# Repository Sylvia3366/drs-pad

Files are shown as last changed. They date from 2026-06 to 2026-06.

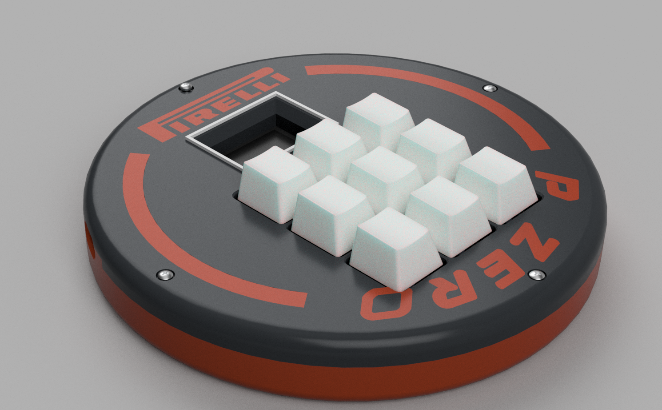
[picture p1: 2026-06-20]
images/drspad_RENDER.png

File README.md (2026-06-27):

# DRS-Pad 🏎️💨
reallygreatsite com

[ONSHAPE CAD](https://cad.onshape.com/documents/f871e0d794d92113bb05b77c/w/53d91f0d4610f412f5f57ae5/e/b5381f3e555c04c2681f8eeb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)
-

What is it? 
-
The DRS-Pad, or Desktop Response System Pad, is a macropad powered by the XIAO-ESP32-S3 with 9 mechanical keys to save your fingers and hasten your workflow so you can be more efficient! Named after the now retired DRS (Drag Reduction System, RIP 2011–2025), the DRS-Pad is modeled after the iconic F1 Pirelli tire (specifically the soft one). Paired with a 1.14" IPS LCD display, it allows you to view race/qualifying results on race/qualification days and WDC/WCC standings on non-race days.

Why did I make it? 
-
First and foremost, I've been wanting to make a macropad for the longest time now. I'm someone who's constantly on my computer—whether it be writing stories, programming/playing games, editing videos, or just doing homework, my fingers are constantly jumping around my keyboard. As a result, I often end the day with cramped fingers, so hopefully, this macropad will solve that :(

As for the theme: I've been an F1 fan for some time now, and I've grown a habit of checking my phone and social media for race updates. But I simply can't do that when I'm in the middle of working on CADing or programming. So I thought, what if I could combine both those problems into one solution?

How does it work?
-
So I made the DRS-Pad! Aside from being your usual, run-of-the-mill macropad for improving workflow and allowing your fingers to rest, there's a little screen that updates you on the latest F1 standings in real time! On a typical, non-race or quali day, the DRS-Pad will flicker between the WDC (driver's championship) and WCC (constructor's championship) every minute. During free practice, quali, and race days, the screen will update every minute with live feed on the current event, displaying the top 9 drivers. This is done through using an open source API **(https://openf1.org)**.

Now, you can save your fingers AND enjoy some nice F1 updates all at the same time :)!

# Designing the PCB 🏁
PCB designed on KiCAD!
-
Screenshot 2026-06-18 at 11 29 14 PM

Screenshot 2026-06-19 at 9 13 22 PM

Screenshot 2026-06-19 at 9 14 33 PM
Screenshot 2026-06-19 at 9 14 27 PM

CADed and assembled on OnShape!
-
Screenshot 2026-06-19 at 9 16 24 PM
Screenshot 2026-06-19 at 9 15 55 PM

Screenshot 2026-06-19 at 9 16 43 PM
Screenshot 2026-06-19 at 9 16 55 PM

Screenshot 2026-06-19 at 9 17 05 PM
Screenshot 2026-06-19 at 9 17 11 PM

Rendered on Fusion360!
-
Screenshot 2026-06-19 at 6 39 32 PM
Screenshot 2026-06-19 at 8 05 35 PM

# Bill of Materials 🧾
| Name | Qty | Unit | Price (USD) | Total (USD) | MOQ | MOQ Price | Source |
| :--- | :---: | :---: | ---: | ---: | ---: | ---: | :--- |
| Seeed Studio XIAO ESP32 S3 | 1 | pcs | 9.46 | 9.46 | 1 | 9.46 | [Link](https://www.aliexpress.us/item/3256808047100037.html) |
| 1.14 inch IPS LCD 135x240 | 1 | pcs | 2.72 | 2.72 | 1 | 2.72 | [Link](https://www.aliexpress.us/item/3256808427301455.html) |
| 1N4148 SOD-123 Diode | 9 | pcs | 0.04 | 0.33 | 100 | 3.70 | [Link](https://www.aliexpress.us/item/3256806021629352.html) |
| Cherry MX Switch | 9 | pcs | 0.77 | 6.95 | 10 | 7.72 | [Link](https://www.aliexpress.us/item/3256808812099705.html) |
| M2 4mm Screws | 4 | pcs | 0.03 | 0.12 | 50 | 1.51 | [Link](https://www.aliexpress.us/item/2251832785290389.html) |
| M2 14mm Screws | 4 | pcs | 0.04 | 0.14 | 50 | 1.75 | [Link](https://www.aliexpress.us/item/2251832785290389.html) |
| PCB | 1 | pcs | 0.80 | 0.80 | 5 | 4.00 | [Link](https://jlcpcb.com) |
| PLA 3D Printed Case | 1 | pcs | - | - | - | - |
| **Total** | **30** | **-** | **-** | **20.52** | **-** | **30.86** | **-** |

# Build and Assembly 🔧

Required Tools
-
1. Solder
2. Soldering iron
3. Tweezers
4. Screwdriver for M2 screws
5. Computer w. a USB port
6. 3D printer

Assembly
-
1. Attach the keycaps onto the switches.
2. Solder the 1N4148 diodes onto the PCB.
3. Solder the remaining parts onto the PCB.
4. Place the assembled PCB into the bottom case.
5. Secure on the mounting holes with M2 4mm screws.
6. Secure the top case on the screw holes with M2 14mm screws (I used 12mm in the CAD, which works).
7. Use Arduino IDE for the firmware.
8. Connect the ESP32 to your computer via USB-C to upload code.
9. Upload firmware.
10. Make sure to change the WiFi so the network matches your own.
11. Test the OLED display and keycaps.
12. Test live updates.

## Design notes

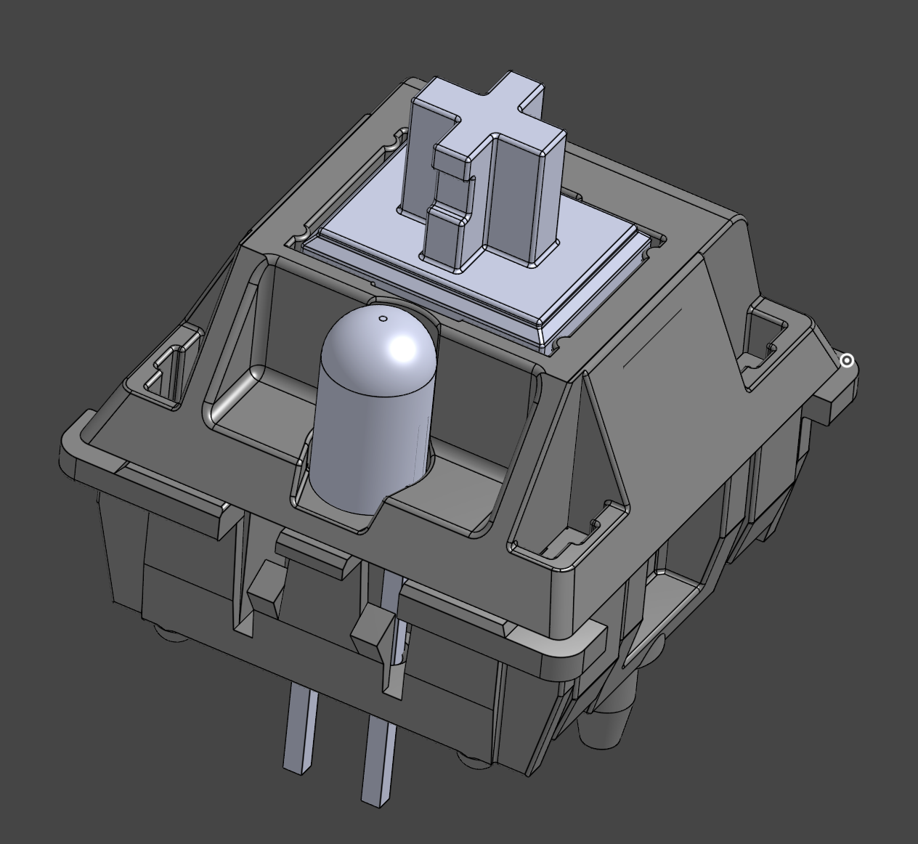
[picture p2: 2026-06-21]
case/CAD/Cherry MX Switches/cherry_mx_switch.png

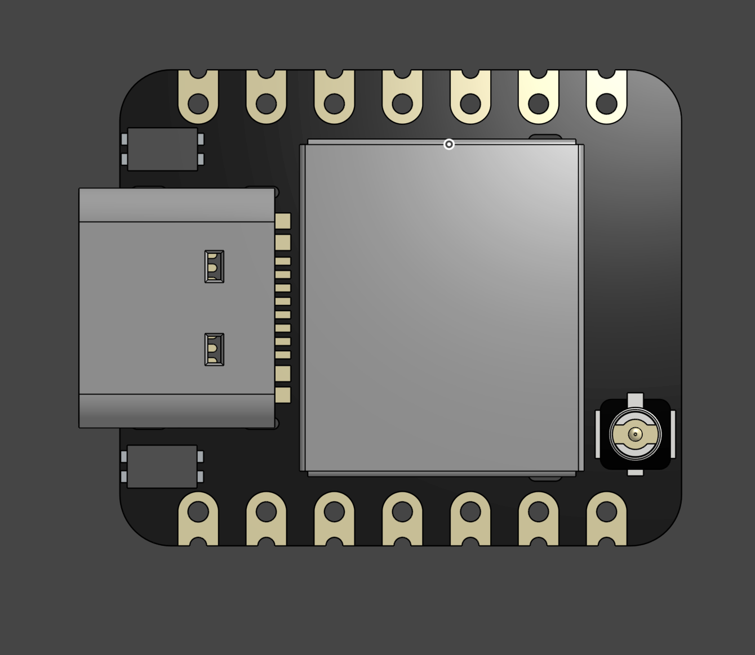
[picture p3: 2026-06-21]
case/CAD/Seeed Studio XIAO-ESP32-S3/xiao-esp32-s3.png

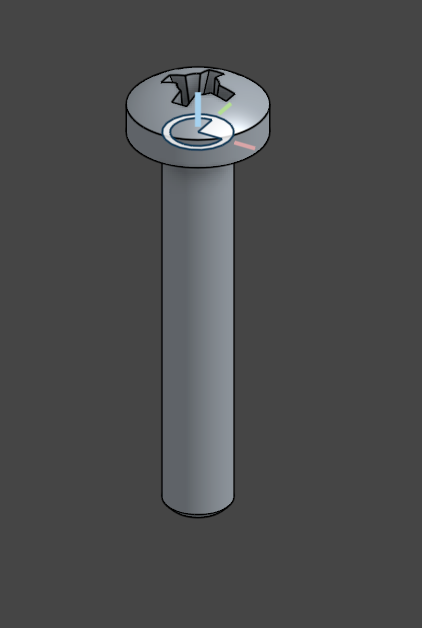
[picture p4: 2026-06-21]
case/CAD/M2 12mm Screw/M2_12mm.png

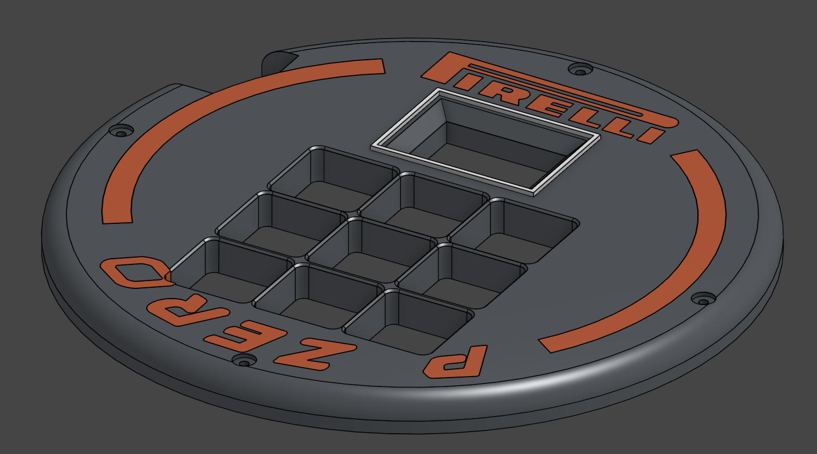
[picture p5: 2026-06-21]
case/Top case/top1.png

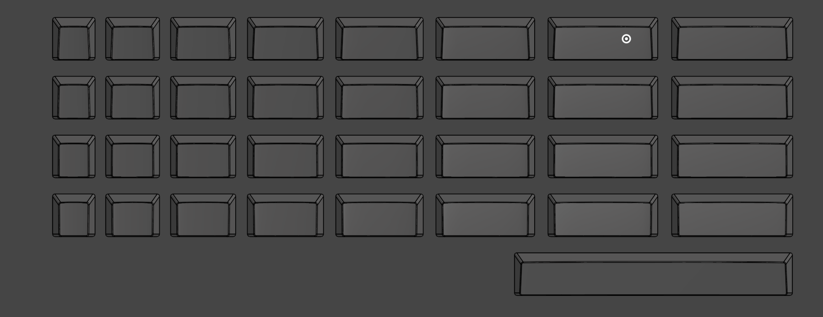
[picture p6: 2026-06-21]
case/CAD/Cherry MX Keycaps/cherry_mx_keycaps.png

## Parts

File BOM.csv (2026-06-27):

Name | Qty | Unit | Price (USD) | Total (USD) | MOQ | MOQ Price (USD) | Source
Seeed Studio XIAO ESP32 S3 | 1 | pcs | 9.46 | 9.46 | 1 | 9.46 | https://www.aliexpress.us/item/3256806801590776.html
1.14 inch IPS LCD 135x240 | 1 | pcs | 2.72 | 2.72 | 1 | 2.72 | https://www.aliexpress.us/item/3256808427301455.html
1N4148 SOD-123 Diode | 9 | pcs | 0.04 | 0.33 | 100 | 3.70 | https://www.aliexpress.us/item/3256806021629352.html
Cherry MX Switch | 9 | pcs | 0.77 | 6.95 | 10 | 7.72 | https://www.aliexpress.us/item/3256808812099705.html
M2 4mm Screws | 4 | pcs | 0.03 | 0.12 | 50 | 1.51 | https://www.aliexpress.us/item/2251832785290389.html
M2 14mm Screws | 4 | pcs | 0.04 | 0.14 | 50 | 1.75 | https://www.aliexpress.us/item/2251832785290389.html
PCB | 1 | pcs | 0.80 | 0.80 | 5 | 4.00 | https://jlcpcb.com
PLA 3D Printed Case | 1 | pcs | - | - | - | - | -
Total | 30 | - | - | 20.52 | - | 30.86 | -

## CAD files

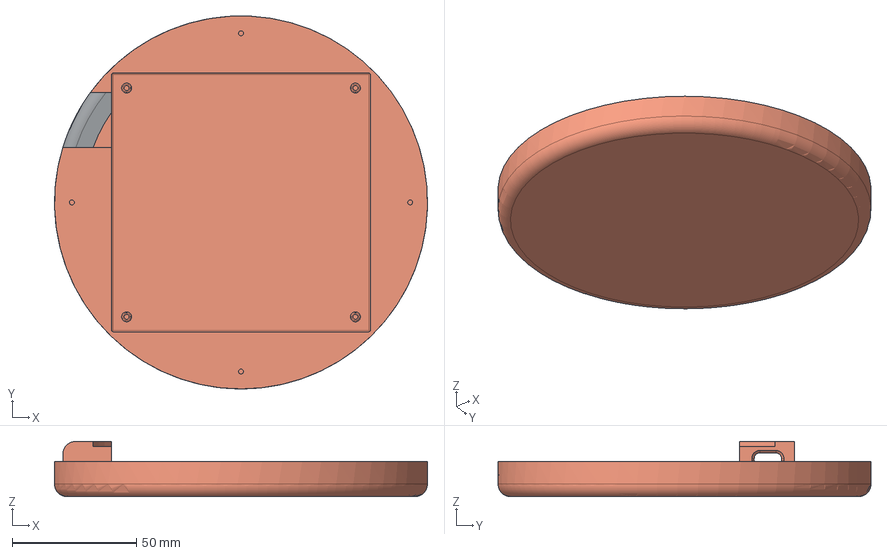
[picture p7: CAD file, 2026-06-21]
case/Bottom case/Bottom Case.step
150.0 x 149.9 x 22.2 mm

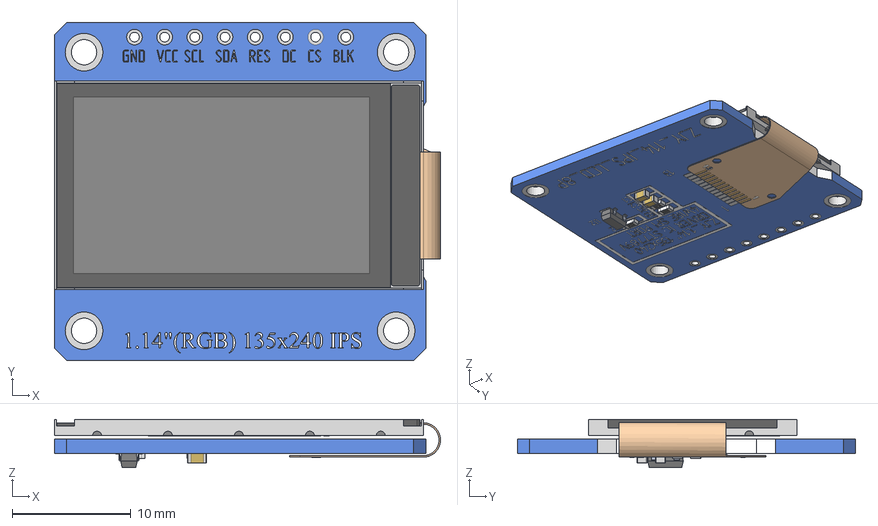
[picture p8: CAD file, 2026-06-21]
case/CAD/1.14" IPS LCD/1.14 TFT IPS - Module.step
32.5 x 28.4 x 4.05 mm
1.14 TFT IPS - Module - Board
0603 Capacitor x 2
0603 Resistor x 3
SOT23
1.14 TFT IPS - 13P - Reverse Mount

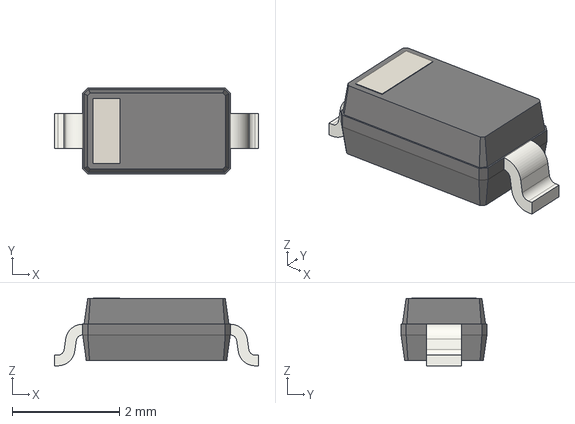
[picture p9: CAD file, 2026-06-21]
case/CAD/1N4148 Diode (SOD-123)/D_SOD-123 (8).step
3.80 x 1.60 x 1.26 mm

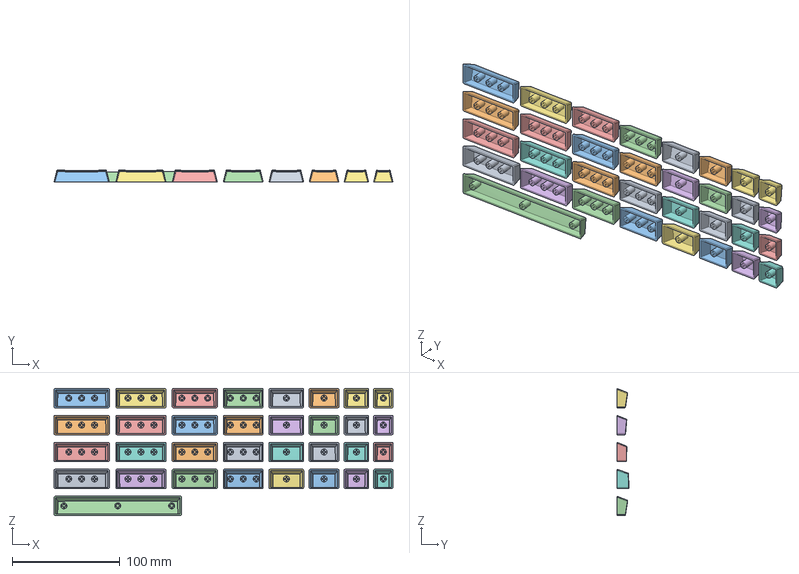
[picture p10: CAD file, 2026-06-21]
case/CAD/Cherry MX Keycaps/Cherry MX keycaps v32.step
314.7 x 11.2 x 118.0 mm
1x1.5 R3 v6
1x1.5 R1 v4
1x1.5 R4 v5
1x1.5 R2 v5
1x1 R3 v8
1x1 R2 v8
1x1 R1 v23
1x1 R4 v6
1x2 R3 v6
1x2 R2 v6
1x2 R4 v6
1x2 R1 v6
1x2.5 R2 v7
1x2.5 R4 v5
1x2.5 R1 v5
1x2.5 R3 v6
1x2.75 R4 v3
1x2.75 R2 v4
1x2.75 R1 v3
1x6.25 R1 v6
1x2.75 R3 v3
1x1.75 R2 v4
1x1.75 R4 v4
1x1.75 R3 v5
1x1.75 R1 v6
1x2.25 R3 v6
1x2.25 R2 v6
1x2.25 R4 v6
1x2.25 R1 v6
1x1.25 R4 v6
1x1.25 R1 v7
1x1.25 R3 v5
1x1.25 R2 v4

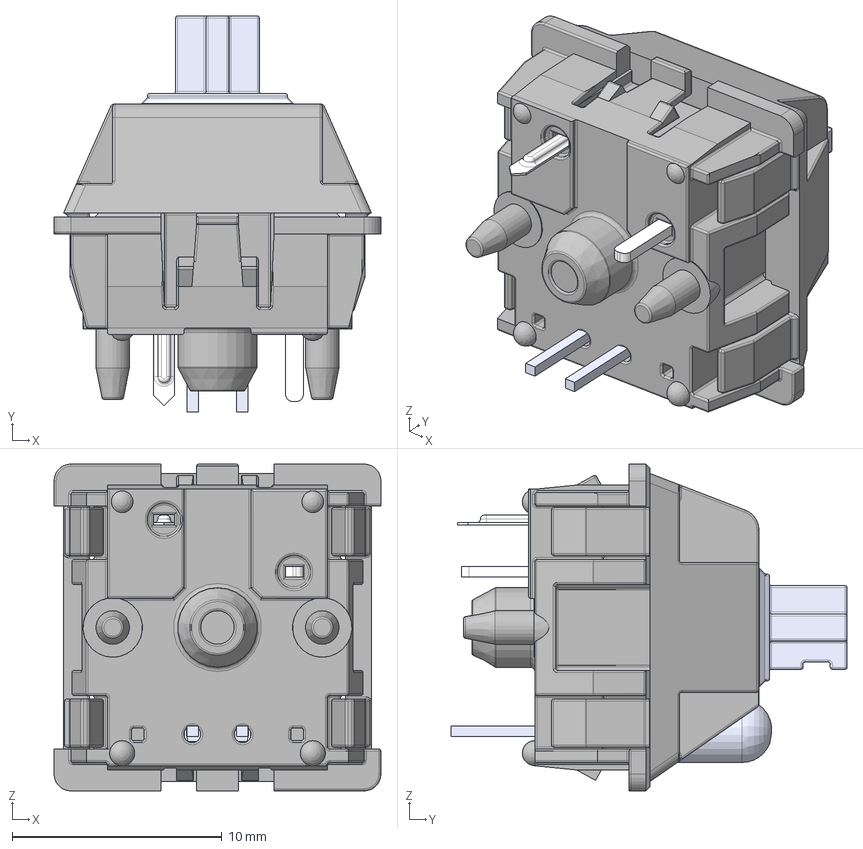
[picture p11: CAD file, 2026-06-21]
case/CAD/Cherry MX Switches/MX 按键_ü_¨1.step
15.6 x 18.9 x 15.6 mm
MX ? ??��_�?�__
MX ? ???_�___�1
MX? ?? ?? ?�2__??_�2____�_
MX? ??LEDLEDLED x 5
??___??__�_ x 2

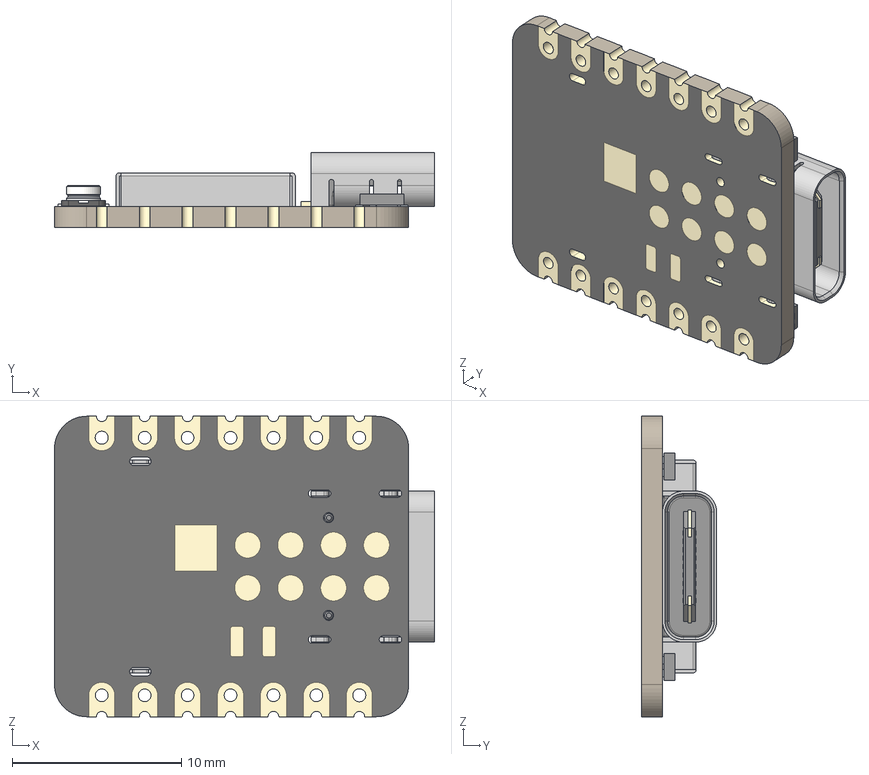
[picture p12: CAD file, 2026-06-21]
case/CAD/Seeed Studio XIAO-ESP32-S3/XIAO-ESP32S3 v2.step
22.5 x 4.46 x 17.8 mm
U.FL-R-SMT-1_10_ v1
Shield
Seeed Studio XIAO-ESP32-S3 (Sense)
Pins x 8
BOSS-EXTRUDE14_6_
BOSS-EXTRUDE7_7_
BOSS-EXTRUDE7_5_
BOSS-EXTRUDE7_4_
BOSS-EXTRUDE14_1_
BOSS-EXTRUDE7_6_
BOSS-EXTRUDE14_12_
BOSS-EXTRUDE14_4_
BOSS-EXTRUDE7_2_
BOSS-EXTRUDE14_2_
BOSS-EXTRUDE14_7_
BOSS-EXTRUDE14_3_
BOSS-EXTRUDE7_1_
BOSS-EXTRUDE7_9_
BOSS-EXTRUDE14_11_
BOSS-EXTRUDE14_9_
BOSS-EXTRUDE14_10_
MIRROR2
BOSS-EXTRUDE14_5_
BOSS-EXTRUDE7_3_
BOSS-EXTRUDE14_8_
BOSS-EXTRUDE7_8_
CUT-EXTRUDE5

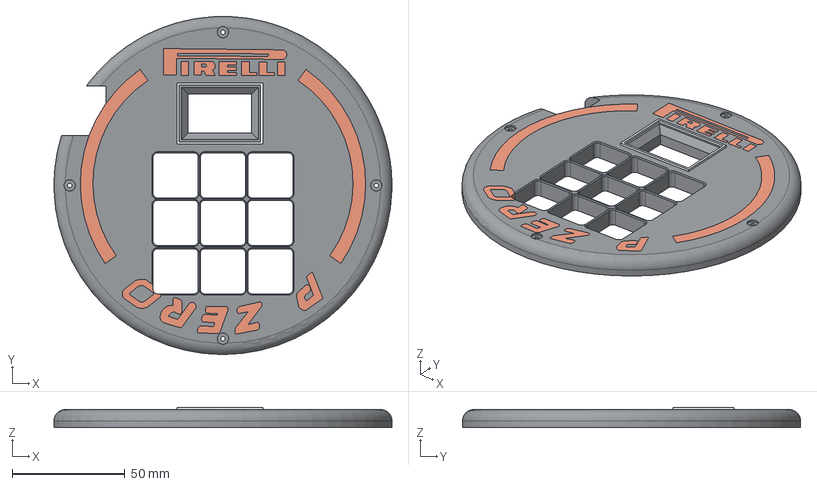
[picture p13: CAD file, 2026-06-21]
case/Top case/Top Case.step
150.0 x 150.0 x 9.00 mm

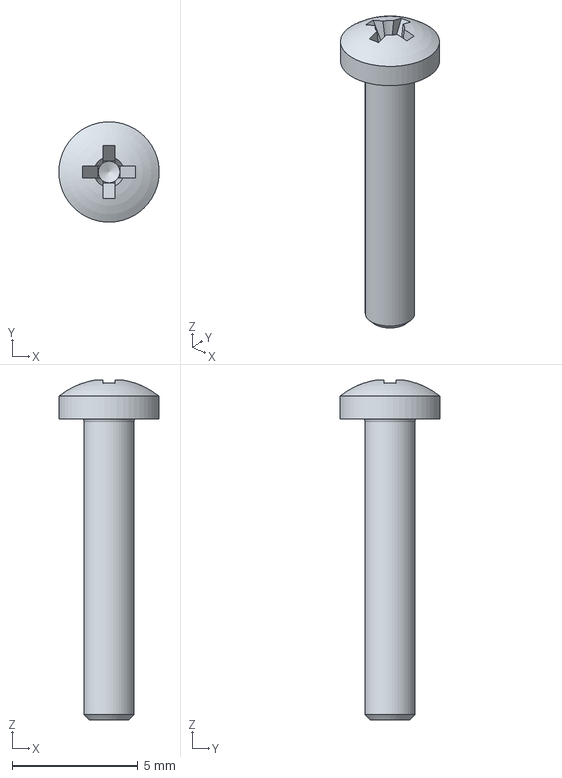
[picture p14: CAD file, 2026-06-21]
case/CAD/M2 12mm Screw/PZ Pan head screw M2x0.40 x 12.step
4.00 x 4.00 x 13.5 mm

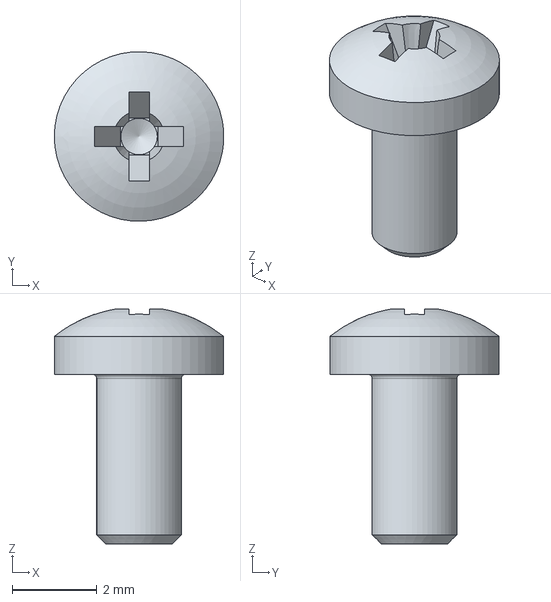
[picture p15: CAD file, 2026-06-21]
case/CAD/M2 4mm Screw/PZ Pan head screw M2x0.40 x 4.step
4.00 x 4.00 x 5.54 mm

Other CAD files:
case/Bottom case/Bottom Case.stl
case/CAD/1.14" IPS LCD/1.14 TFT IPS - Module.stl
case/CAD/1N4148 Diode (SOD-123)/D_SOD-123 (8).stl
case/CAD/Cherry MX Keycaps/Cherry MX keycaps v32.stl
case/CAD/Cherry MX Switches/MX 按键_ü_¨1.stl
case/CAD/M2 12mm Screw/PZ Pan head screw M2x0.40 x 12.stl
case/CAD/M2 4mm Screw/PZ Pan head screw M2x0.40 x 4.stl
case/CAD/Seeed Studio XIAO-ESP32-S3/XIAO-ESP32S3 v2.stl
case/Top case/Top Case.stl

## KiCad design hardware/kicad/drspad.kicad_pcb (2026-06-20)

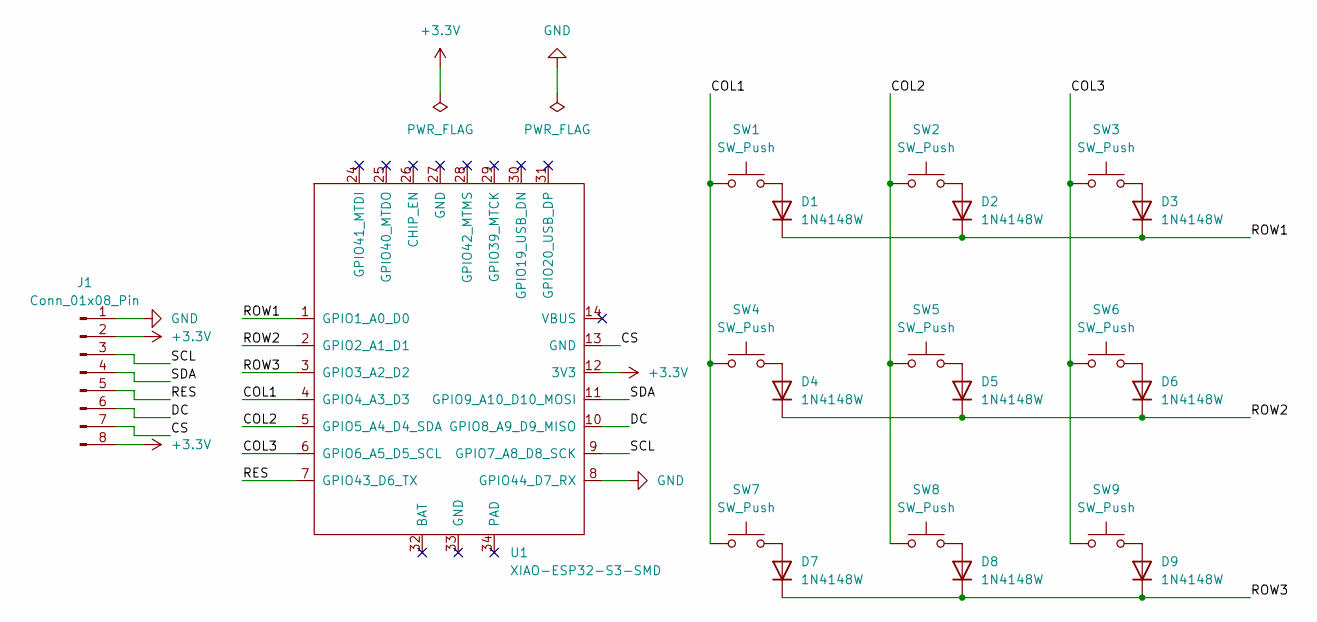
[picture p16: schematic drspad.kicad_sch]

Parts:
D1, D2, D3, D4, D5, D6, D7, D8, D9: 1N4148W; D_SOD-123
J1: Conn_01x08_Pin; PinHeader_1x08_P2.54mm_Vertical
SW1, SW2, SW3, SW4, SW5, SW6, SW7, SW8, SW9: SW_Push; SW_Cherry_MX_1.00u_PCB
U1: XIAO-ESP32-S3-SMD; XIAO-ESP32-S3-DIP

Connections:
+3.3V: J1.2, J1.8, U1.12 (3V3)
/COL1: SW1.1, SW4.1, SW7.1, U1.4 (GPIO4_A3_D3)
/COL2: SW2.1, SW5.1, SW8.1, U1.5 (GPIO5_A4_D4_SDA)
/COL3: SW3.1, SW6.1, SW9.1, U1.6 (GPIO6_A5_D5_SCL)
/CS: J1.7, U1.13 (GND)
/DC: J1.6, U1.10 (GPIO8_A9_D9_MISO)
/RES: J1.5, U1.7 (GPIO43_D6_TX)
/ROW1: D1.1 (K), D2.1 (K), D3.1 (K), U1.1 (GPIO1_A0_D0)
/ROW2: D4.1 (K), D5.1 (K), D6.1 (K), U1.2 (GPIO2_A1_D1)
/ROW3: D7.1 (K), D8.1 (K), D9.1 (K), U1.3 (GPIO3_A2_D2)
/SCL: J1.3, U1.9 (GPIO7_A8_D8_SCK)
/SDA: J1.4, U1.11 (GPIO9_A10_D10_MOSI)
GND: J1.1, U1.8 (GPIO44_D7_RX)
unnamed: D1.2 (A), SW1.2
unnamed: D2.2 (A), SW2.2
unnamed: D3.2 (A), SW3.2
unnamed: D4.2 (A), SW4.2
unnamed: D5.2 (A), SW5.2
unnamed: D6.2 (A), SW6.2
unnamed: D7.2 (A), SW7.2
unnamed: D8.2 (A), SW8.2
unnamed: D9.2 (A), SW9.2

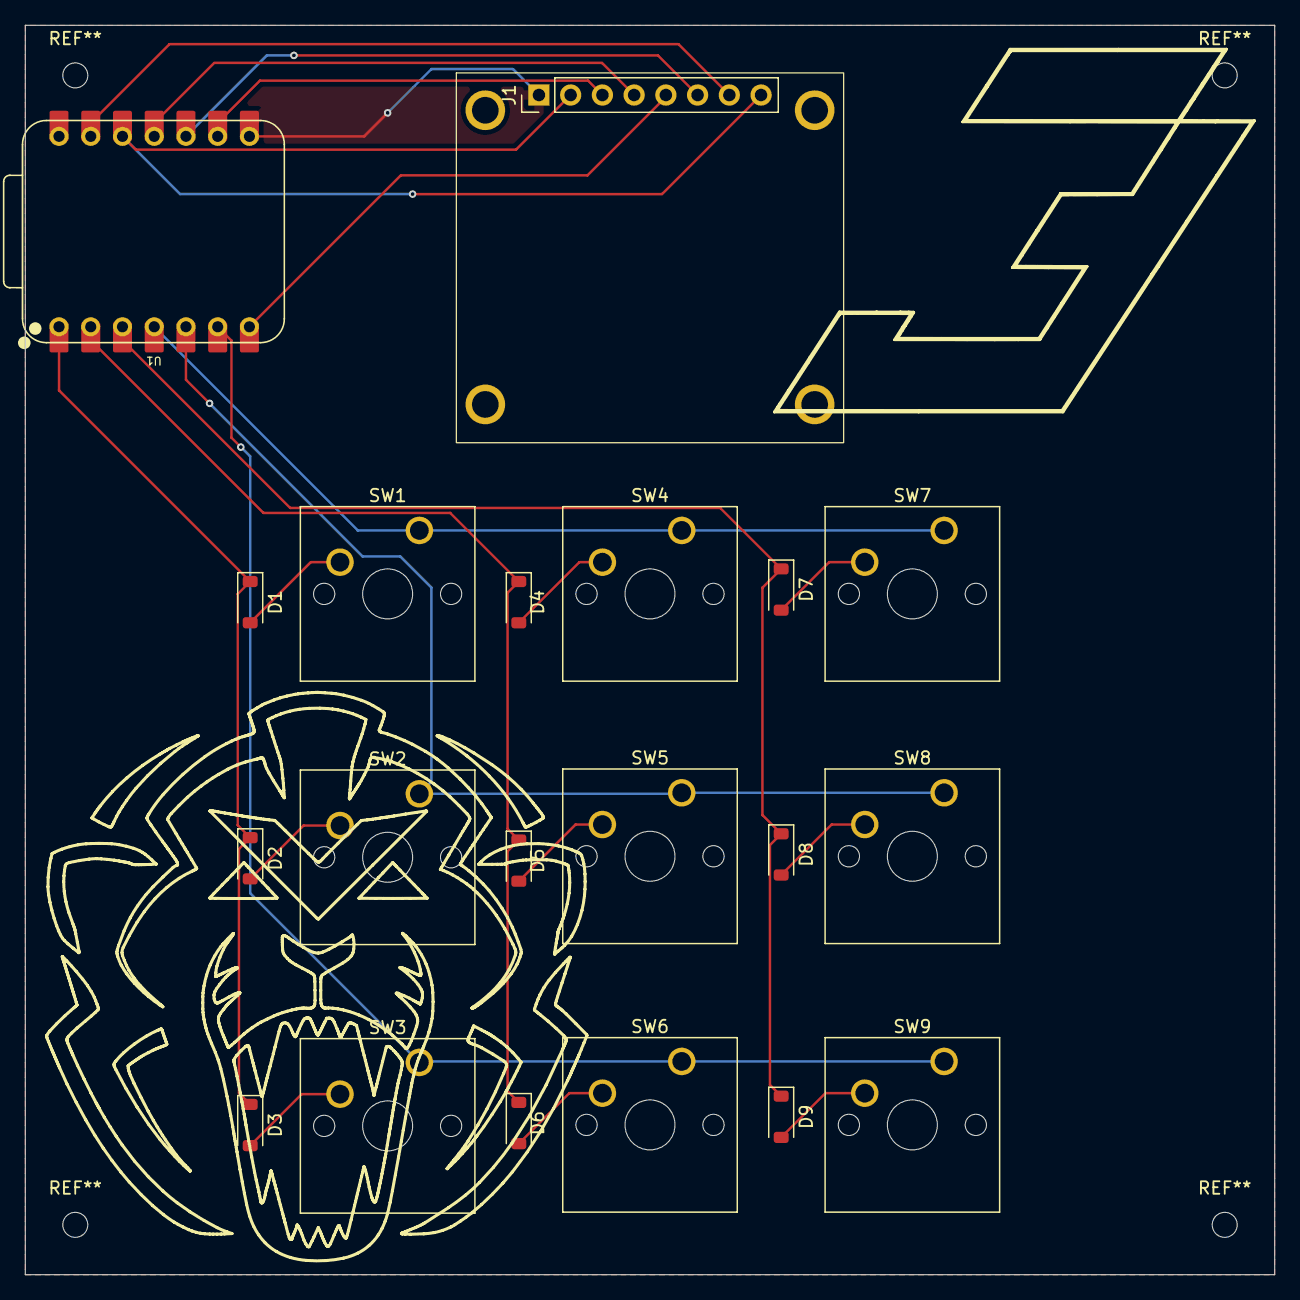
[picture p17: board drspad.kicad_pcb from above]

Board: 2 copper layers, 100.0 x 100.0 mm, 20 parts (0 on the bottom side), 22 nets.

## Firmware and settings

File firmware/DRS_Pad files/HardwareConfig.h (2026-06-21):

#ifndef HARDWARE_CONFIG_H
#define HARDWARE_CONFIG_H

#define TFT_MOSI 10
#define TFT_SCLK 7
#define TFT_DC 8
#define TFT_CS -1
#define TFT_RST 43

#define ROW1 1
#define ROW2 2
#define ROW3 3
#define COL1 4
#define COL2 5
#define COL3 6

const int rowPins[] = {1,2,3};
const int colPins[] = {4,5,6};

#endif

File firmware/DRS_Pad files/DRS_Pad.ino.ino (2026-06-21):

#include "USBHIDKeyboard.h"
#include <TFT_eSPI.h>
#include "HardwareConfig.h"

const uint8_t keyMap[] = {
  KEY_F1, KEY_F2, KEY_F3,
  KEY_F4, KEY_F5, KEY_F6,
  KEY_F7, KEY_F8, KEY_F9
};

void connectToWiFi();
void drawStaticGrid();
void scanKeyMatrix();
void fetchF1Data();

USBHIDKeyboard Keyboard;
TFT_eSPI tft = TFT_eSPI();
unsigned long lastFetch = 0;

void setup() {
  Serial.begin(115200);
  delay(1000);
  //wifi
  connectToWiFi();
  //hardware
  Keyboard.begin();
  tft.init();
  tft.setRotation(1); //or 3, check when building
  //ui
  drawStaticGrid();
  fetchF1Data();
}

unsigned long lastSwitchTime = 0;
const unsigned long interval = 60000;
bool showWDC = true;

vvoid loop() {
  unsigned long currentTime = millis();

  if (WiFi.status() != WL_CONNECTED) {
    connectToWiFi();
  }

  if (isRaceDay) {
    if (currentTime - lastFetch >= 60000) {
      fetchF1Data();
      lastFetch = currentTime;
    }
  } else {
    if (currentTime - lastSwitchTime >= interval) {
      lastSwitchTime = currentTime;
      showWDC = !showWDC; 
      refreshDisplay();
    }
  }

  scanKeyMatrix();
}
